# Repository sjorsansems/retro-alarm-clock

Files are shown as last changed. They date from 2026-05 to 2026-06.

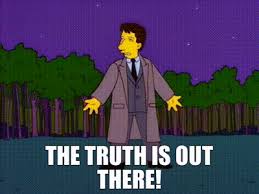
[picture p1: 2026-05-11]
animations/images.jpg

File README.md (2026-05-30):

# Retro Georgy Alarm Clock (ESP32 + MicroPython)

```text
██████╗ ███████╗████████╗██████╗  ██████╗      █████╗ ██╗      █████╗ ██████╗ ███╗   ███╗
██╔══██╗██╔════╝╚══██╔══╝██╔══██╗██╔═══██╗    ██╔══██╗██║     ██╔══██╗██╔══██╗████╗ ████║
██████╔╝█████╗     ██║   ██████╔╝██║   ██║    ███████║██║     ███████║██████╔╝██╔████╔██║
██╔══██╗██╔══╝     ██║   ██╔══██╗██║   ██║    ██╔══██║██║     ██╔══██║██╔══██╗██║╚██╔╝██║
██║  ██║███████╗   ██║   ██║  ██║╚██████╔╝    ██║  ██║███████╗██║  ██║██║  ██║██║ ╚═╝ ██║
╚═╝  ╚═╝╚══════╝   ╚═╝   ╚═╝  ╚═╝ ╚═════╝     ╚═╝  ╚═╝╚══════╝╚═╝  ╚═╝╚═╝  ╚═╝╚═╝     ╚═╝

		  8-BIT OLED ANIMATIONS  +  MP3 ALARM MUSIC  +  WS2812 LED THEMES
```


An ESP32-S3 retro alarm clock project with:
- SH1106 OLED 128x64 display and pixel animations
- DFPlayer Mini MP3 alarm playback
- WS2812 LED strip  (8 leds) effects per alarm theme
- DS3231 RTC support (with optional EEPROM schedule storage)
- WiFi time sync (NTP), weather data, and web configuration UI
- Setup AP fallback (`AlarmKlok-Setup`) when WiFi is not configured/reachable

## What We Built


This project is a complete standalone alarm device, not only a demo sketch.

Main features:
- Clock display with big 8-bit style digits
- Weekly alarm scheduling
- One-tap "skip next alarm once"
- Snooze support
- Theme-based Retro (games) alarm playback (audio + display animation + LEDs)
- A tool to convert (small) gif images to bin files which can be used as a alarmclock animation.
- OTA updates via browser
- Setup access point mode for first-time WiFi setup
- Safe boot fallback to backup app after repeated boot failures
- Built-in Phoenix-style mini Space Game (3-button controls + optional game music)

## Demo Video

A short demo video is included in:

- `video/VID_20260530_151530653.mp4`

Note: this file is stored with Git LFS. Depending on your browser/GitHub view, inline playback may not always work.
If playback is unavailable, open the file page and download it to view locally.

## 3D Print Files (STL)

3D printable enclosure/model files are included in:

- `stl files/front.stl`
- `stl files/back.stl`
- `stl files/button.stl`
- `stl files/buttonholders.stl`

You can slice and print these parts to build the physical case.

## Hardware Requirements

- 1x ESP32-S3 DevKitC-1 -> I used a N16R8, other models not tested. Enough Ram is mandantory. 
- 1x SH1106 OLED display (128x64, I2C)
- 1x DS3231 RTC module (I2C)
- Optional: AT24C32 EEPROM on RTC board (for schedule persistence)
- 1x DFPlayer Mini MP3 module + speaker
- 1x WS2812/NeoPixel LED strip (configured for 8 LEDs)
- 3x push buttons
- Wires + common GND
- Recommended: 1k resistor on ESP32 TX -> DFPlayer RX line

## Pin Mapping (Current v6)

| Function | ESP32 Pin | Notes |
|---|---:|---|
| OLED SDA | GPIO8 | SH1106 I2C bus |
| OLED SCL | GPIO9 | SH1106 I2C bus |
| RTC SDA | GPIO5 | Dedicated RTC I2C bus |
| RTC SCL | GPIO6 | Dedicated RTC I2C bus |
| DFPlayer TX (ESP->DF RX) | GPIO17 | Use 1k series resistor |
| DFPlayer RX (ESP<-DF TX) | GPIO18 | Direct is fine |
| WS2812 Data | GPIO2 | GRB byte order |
| Button UP | GPIO12 | Short: nightlight toggle, Long (3s): start Space Game |
| Button DOWN | GPIO13 | Short: OLED mode, Long: WiFi toggle |
| Button SET | GPIO14 | Short: skip next alarm once, Long: alarm edit |

## Wiring Overview

### OLED (SH1106)
- VCC -> 3.3V
- GND -> GND
- SDA -> GPIO8
- SCL -> GPIO9

### RTC (DS3231)
- VCC -> 3.3V
- GND -> GND
- SDA -> GPIO5
- SCL -> GPIO6

### DFPlayer Mini
- VCC -> 5V preferred (or stable 3.3V if your module supports it)
- GND -> GND (shared with ESP32)
- DF RX <- ESP GPIO17 (through 1k resistor)
- DF TX -> ESP GPIO18
- SPK_1/SPK_2 -> Speaker

### WS2812 LED Strip
- DIN <- GPIO2
- VCC -> external 5V (recommended)
- GND -> GND (must be shared with ESP32)

### Buttons
- One side of each button -> GPIO12 / GPIO13 / GPIO14
- Other side -> GND
- Internal pull-ups are enabled in firmware

## Software Requirements

- MicroPython firmware on ESP32-S3
- Python 3.10+ on your PC
- `mpremote` for USB deployment (optional if you only use OTA)

Optional local tooling:
- FFmpeg (audio conversion)

## Project Structure (Important Files)

- `main.py` -> boot entrypoint with safe-mode fallback logic
- `retro_georgy_alarm_klok_v6.py` -> main application
- `retro_georgy_alarm_klok_v6_backup.py` -> backup runtime target
- `index_v6.html` -> web UI served by the device
- `config_manager.py` -> config defaults/load/save
- `config.example.json` -> safe config template for repo sharing
- `neopixel_driver.py`, `dfplayer.py`, `ds3231.py` -> hardware drivers

## Installation

### 1. Flash MicroPython
Flash an ESP32-S3 MicroPython firmware compatible with your board.

### Optional: Web Installer (WLED-style)

this repo includes an ESP Web Tools setup.
But you can also install Microphthon yourself en use the Powershell script included.

- `web-installer/install.html`
- `web-installer/manifest.json`

Usage:

1. Ensure `web-installer/manifest.json` points to a valid ESP32-S3 firmware `.bin`.
2. Publish your repo with GitHub Pages.
3. Open `https://<your-user>.github.io/<your-repo>/web-installer/install.html`.
4. Click **Install Alarm Clock Firmware** and select your board serial port.

Live installer URL for this project:

- https://sjorsansems.github.io/retro-alarm-clock/web-installer/install.html

Important:

- Web Serial only works on secure pages (`https://`) in compatible browsers (Chrome/Edge).
- This web installer flashes firmware only.

After flashing, run one command in PowerShell to deploy app files:

```powershell
powershell -ExecutionPolicy Bypass -Command "iwr https://raw.githubusercontent.com/sjorsansems/retro-alarm-clock/main/tools/deploy_web_installer.ps1 -OutFile deploy_alarmklok.ps1; ./deploy_alarmklok.ps1 -Port COM7"
```

Change `COM7` if your device uses another port.

### 2. Clone the Project

```bash
git clone <your-repo-url>
cd AlarmKlok
```

### 3. Prepare Configuration

Use `config.example.json` as your base and create local `config.json` (not tracked in git).

### 4. Deploy to Device

USB deployment example:

```bash
python -m mpremote connect COM7 + cp main.py :main.py + cp retro_georgy_alarm_klok_v6.py :retro_georgy_alarm_klok_v6.py + cp retro_georgy_alarm_klok_v6_backup.py :retro_georgy_alarm_klok_v6_backup.py + cp config_manager.py :config_manager.py + cp index_v6.html :index_v6.html + cp config.json :config.json + reset
```

### 5. First Boot / Setup AP

If WiFi is not configured or unavailable, the device starts AP mode:
- SSID: `AlarmKlok-Setup`
- IP: `192.168.4.1`

Connect to that network, open the page, and save your WiFi credentials.

## Web Interface

When connected to your home network, open the device IP in your browser.

You can configure:
- Current time and seconds
- Timezone and UI language
- Alarm schedule per weekday
- Alarm test playback
- Weather location and update behavior
- WiFi behavior and setup credentials
- OTA file uploads
- GitHub Pages update checks and installs
- Retro Fact display duration and quick test
- DOS Idle Chaos screensaver behavior and daily limit
- Space Game music selection and quick start from web UI

## Automatic Updates via GitHub Pages

This project supports update checks against a GitHub Pages manifest:

- Manifest location (default): `updates/stable/manifest.json`
- Example URL: `https://sjorsansems.github.io/retro-alarm-clock/updates/stable/manifest.json`

How it works:

1. Clock checks the manifest URL.
2. If `version` is newer than the running app version, update is marked as available.
3. On install, files in manifest `files[]` are downloaded and swapped in place.
4. Clock schedules an automatic reboot.

Manifest format:

```json
{
	"version": "6.1.0",
	"channel": "stable",
	"files": [
		{
			"path": "retro_georgy_alarm_klok_v6.py",
			"url": "https://sjorsansems.github.io/retro-alarm-clock/updates/stable/retro_georgy_alarm_klok_v6.py",
			"sha256": "optional-hex-sha256"
		}
	]
}
```

Use the web UI card **GitHub Auto-Update** to:

- Enable/disable automatic checks
- Set check interval (hours)
- Change manifest URL
- Run manual check/install
- See an install progress bar while update is running

## User Guide (Buttons)

Normal clock screen:
- `UP` short press -> Nightlight ON/OFF
- `UP` long press (3s) -> Start Space Game
- `DOWN` short press -> Cycle OLED brightness modes
- `DOWN` long press -> WiFi ON/OFF
- `SET` short press -> Skip next scheduled alarm once
- `SET` long press -> Enter alarm edit mode

During alarm:
- `SET` -> Stop alarm
- `DOWN` -> Snooze (10 minutes)

During Space Game (Phoenix-style):
- `SET` (left/alarm button) -> Move ship left
- `UP` (middle/nightlight button) -> Shoot
- `DOWN` (right/dim button) -> Move ship right
- `UP` long press (3s) -> Exit game

Alarm edit mode:
- `UP` -> Hour +1
- `DOWN` -> Minute +1
- `SET` long press -> Save

## Safe Boot / Fallback Mode

`main.py` tracks startup failures.
- Primary app: `retro_georgy_alarm_klok_v6`
- Backup app: `retro_georgy_alarm_klok_v6_backup`

After repeated boot failures, it switches to backup mode automatically.

## Music and Animations

- DFPlayer supports multiple numbered tracks
- Theme mapping controls LED + animation style per alarm tone
- Additional animation binaries (`.bin`) can be uploaded via web UI

### DFPlayer MP3 File Order (Required)

`0001.mp3` is the intro track and is included in this repository.

For built-in alarm tones/animations, users should add their own files in this exact order:

1. `0001.mp3` -> Intro (already in repo)
2. `0002.mp3` -> Zelda
3. `0003.mp3` -> Mario
4. `0004.mp3` -> Synthwave
5. `0005.mp3` -> Sonic
6. `0006.mp3` -> Metroid
7. `0007.mp3` -> Pokemon
8. `0008.mp3` -> Tetris
9. `0009.mp3` -> Moonstone
10. `0010.mp3` -> Arcade
11. `0011.mp3` -> DOOM
12. `0012.mp3` -> Knight Rider
13. `0013.mp3` -> Fire
14. `0014.mp3` -> Heartbeat
15. `0015.mp3` -> Matrix
16. `0016.mp3` -> Pac-Man
17. `0017.mp3` -> Pong
18. `0018.mp3` -> Radar
19. `0019.mp3` -> Skull
20. `0020.mp3` -> Snake
21. `0021.mp3` -> Space
22. `0022.mp3` -> UFO
23. `0023.mp3` -> Donkey

Notes:

- Use zero-padded names (`0002.mp3`, not `2.mp3`).
- Place files in DFPlayer root.
- Keep numbering stable after first setup.

### Custom Uploads: Matching Music and Animations in Web UI

After uploading custom `.bin` animations in **Animaties beheren**:

1. Use the **Muziek** dropdown to choose the MP3 track mapping.
2. Use the **LED** dropdown to choose the LED theme mapping.
3. Click **Save** per animation.

This allows user-uploaded animations to use any preferred track and LED style.

### Retro Facts

When you stop the alarm, the clock can show a short retro-game fact on the display.

How it works:

1. The firmware picks a fact from a local retro-game library based on the date.
2. This works fully offline, so no internet connection is required.
3. The fact is deterministic per day, so the same date shows the same retro fact.
4. Long facts scroll vertically with a short pause before moving.

The web UI also includes a **Retro Fact Test** card so you can:

1. Set how many seconds the fact stays on screen.
2. Use the same duration for both manual test and normal alarm-stop flow.
3. Preview the local fact without triggering the alarm.

### DOS Idle Chaos

The clock now supports a DOS-style idle screensaver with random retro error scenes.

Included concepts:

1. Funny/absurd prompts
2. DOS/boot-style setup failures
3. Creepy virus-style warnings

How it behaves:

1. It triggers after configurable idle minutes.
2. Scenes switch every few seconds to look unstable.
3. A per-day maximum controls how often it can appear.
4. You can trigger it manually via **Test DOS chaos** in the web UI.

Related files:

- `create_dos_animation.py` (generator script)
- `animations/dos_meltdown.gif`
- `animations/dos_meltdown.bin`

### Space Game (Phoenix-style)

The clock now includes a compact Space Game inspired by classic fixed-shooter gameplay.

Implemented gameplay set:

1. Four classic bird-like enemy sprite variants with 2-frame flap animation.
2. Per-wave behavior patterns (march, zig-zag, and dive waves).
3. Phoenix-style cadence and tempo scaling (enemy step speed + shot burst pressure increase per wave).
4. LED strip rhythm mapped to gameplay phase (different color pulse profiles, hit flash, shot flash, wave-clear pulse).
5. Bonus mothership phase every 5th wave with its own HP bar and attack pattern.

How to start:

1. Hold the middle nightlight button (`UP`) for 3 seconds.
2. Or press **Start Space game nu** in the web UI.

Controls:

1. Left button (`SET`) moves left.
2. Middle button (`UP`) shoots.
3. Right button (`DOWN`) moves right.
4. Hold middle (`UP`) for 3 seconds to exit.

Web UI settings:

1. Use the **Space Game (Phoenix-style)** card.
2. Select game music in the dropdown (same track label style used in **Animaties beheren**).
3. Save with **Space game instellingen opslaan**.

### GIF to BIN Tool (How to Use)

You can convert small GIF animations to the `.bin` format used by the clock.

Requirements:

- Python 3.10+
- Pillow (`pip install pillow`)

Converter script:

- `tools/gif_to_frames.py`

Example command:

```bash
python tools/gif_to_frames.py --input animations/mario.gif --output animations/mario.bin --width 128 --height 64 --fps 12 --bin
```

Recommended settings:

- Keep source GIF short (2-8 seconds)
- Low frame rate (8-15 fps) to reduce file size
- High contrast source for better 1-bit conversion quality

Upload workflow:

1. Open the clock web UI.
2. Go to **Animaties beheren**.
3. Upload your generated `.bin` file.
4. Optionally map that animation to music/LED theme in the same UI.

Notes:

- Large `.bin` files may fail upload if free storage is low.
- Use `/api/storage-info` (shown in UI) to check available upload space.

See `MUSIC_GUIDE.md` for detailed music sourcing and preparation.

## Troubleshooting

No OLED output:
- Check I2C wiring and 3.3V power

No RTC detected:
- Verify DS3231 pins on dedicated bus (GPIO5/GPIO6)

No DFPlayer sound:
- Verify UART wiring, power, and shared GND
- Check speaker and SD content

No WiFi page:
- Check if AP mode is active (`AlarmKlok-Setup`)
- Otherwise verify station network connectivity

## License / Sharing Notes

- `config.json` is local-only and ignored by git
- Share `config.example.json` instead
- Do not commit personal WiFi credentials

---

```text
PRESS START TO WAKE UP.
```

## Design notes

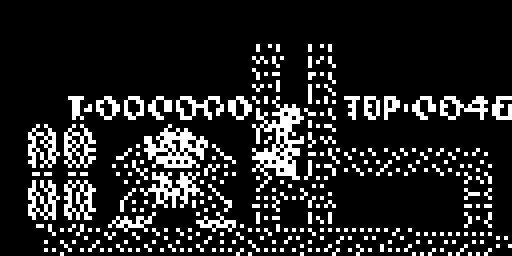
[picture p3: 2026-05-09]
donkey_preview.png

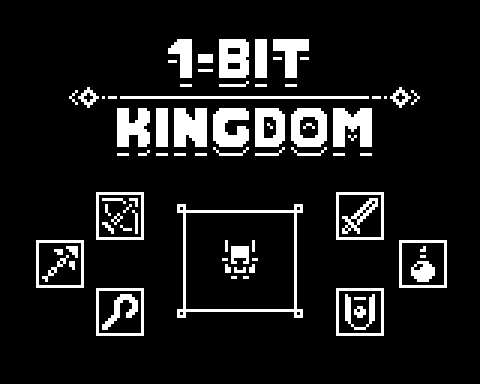
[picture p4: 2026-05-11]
animations/1bit-kingdom.gif

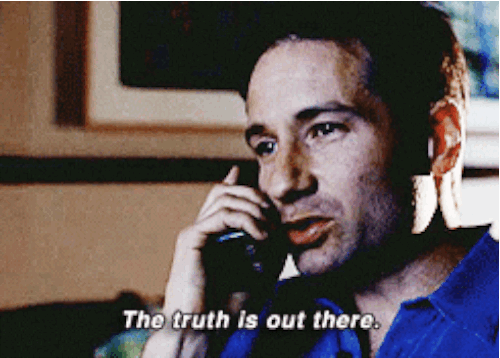
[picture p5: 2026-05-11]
animations/xfiles.gif

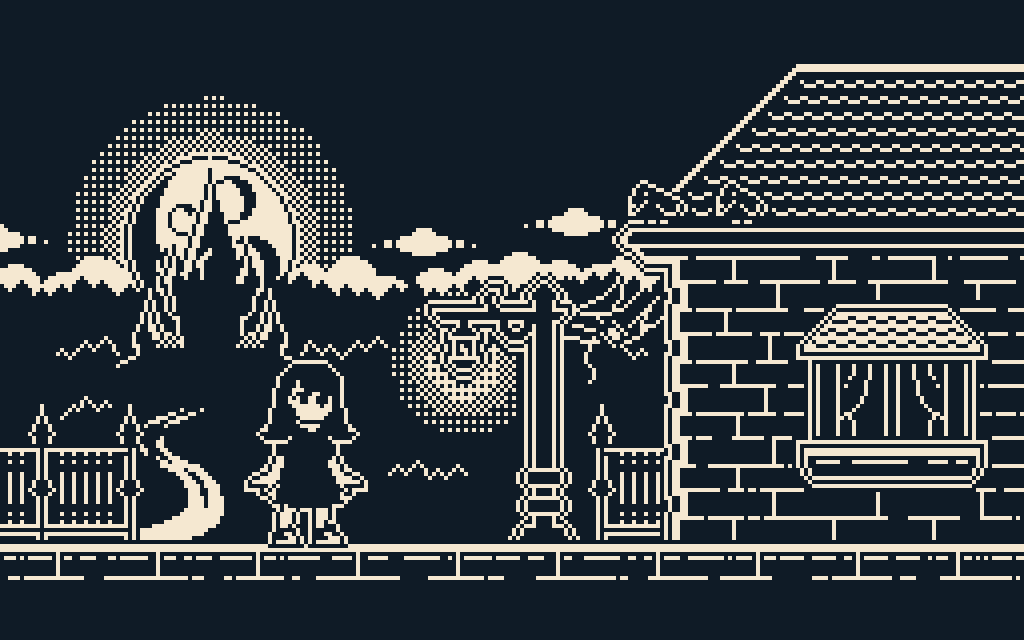
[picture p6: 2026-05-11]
animations/gothic.gif

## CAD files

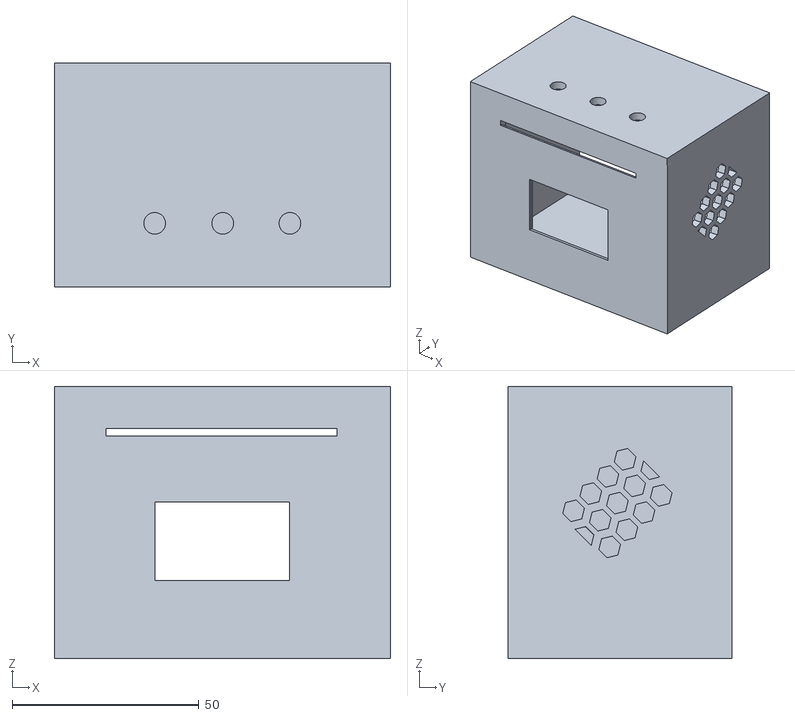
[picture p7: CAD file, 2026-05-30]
stl files/front.stl
90.0 x 60.0 x 73.0

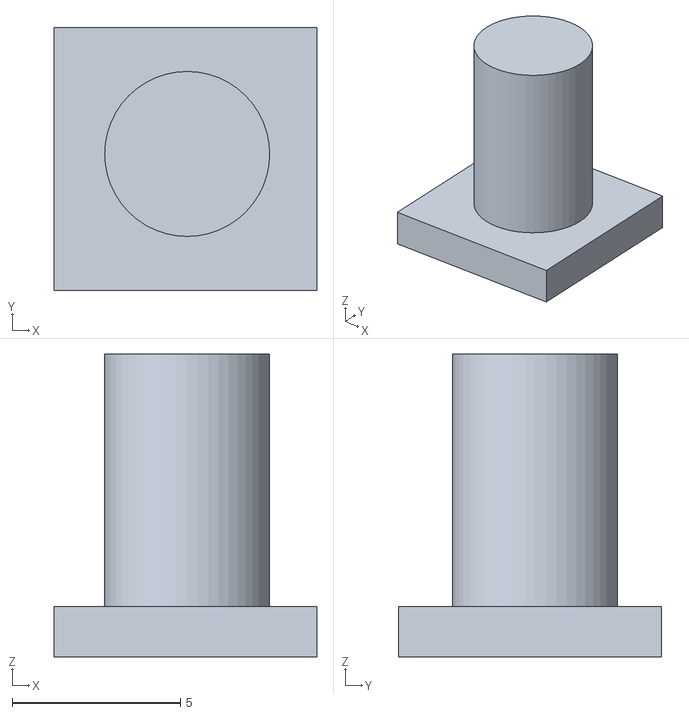
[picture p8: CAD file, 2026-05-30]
stl files/button.stl
7.80 x 7.80 x 9.00

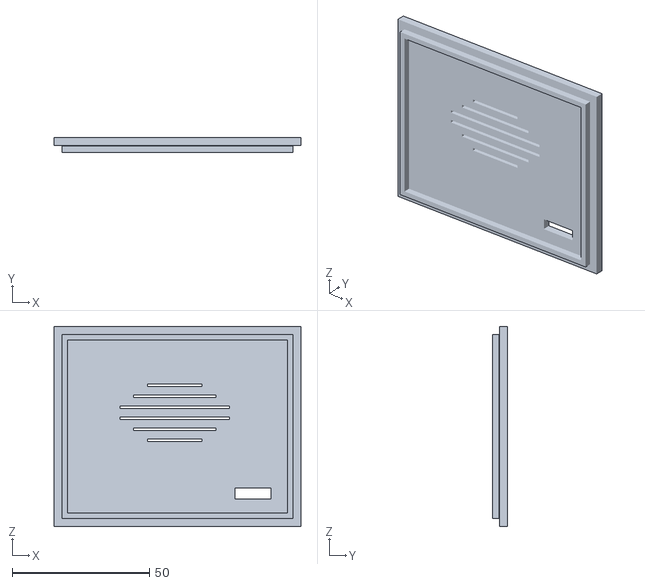
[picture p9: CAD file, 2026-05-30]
stl files/back.stl
90.0 x 5.60 x 73.0

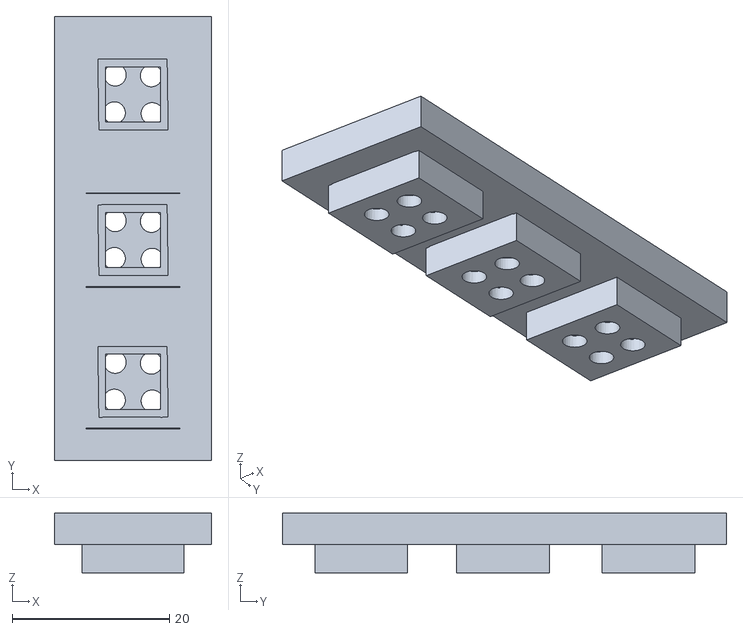
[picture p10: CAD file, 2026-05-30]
stl files/buttonholders.stl
20.0 x 56.4 x 7.60

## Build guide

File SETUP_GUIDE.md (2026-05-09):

# ESP32 Alarmklok - Setup Guide

## 📌 Hardware Verbindingen

### ESP32 Pinout Overzicht

| ESP32 Pin | Gebruik | Component | Opmerking |
|---|---|---|---|
| GPIO8 | I2C SDA | OLED (SH1106) | I2C bus voor display |
| GPIO9 | I2C SCL | OLED (SH1106) | I2C bus voor display |
| GPIO5 | I2C SDA | DS3231 RTC | Aparte I2C bus voor RTC |
| GPIO6 | I2C SCL | DS3231 RTC | Aparte I2C bus voor RTC |
| GPIO13 | Knop UP (SET) | Bedieningsknop | Ingang met pull-up, knop naar GND |
| GPIO12 | Knop DOWN (ALARM) | Bedieningsknop | Ingang met pull-up, knop naar GND |
| GPIO14 | Knop SET | Bedieningsknop | Ingang met pull-up, knop naar GND |
| GPIO17 | UART1 TX | DFPlayer Mini RX | Via 1k ohm serieweerstand |
| GPIO18 | UART1 RX | DFPlayer Mini TX | Direct verbinden |
| GPIO27 | Buzzer + | Buzzer/Speaker | Niet gebruikt in huidige versie |
| GPIO2 | LED data | WS2812 (NeoPixel) | Bitstream, byte-order GRB |
| 3.3V | Voeding + | OLED + DS3231 | Gebruik 3.3V, niet 5V |
| GND | Massa | Alle modules | Gemeenschappelijke ground |

Niet gebruikt in deze basissetup: alle overige GPIO's.

### OLED Display (I2C - 1.3" SH1106)
```
OLED Pin    ESP32 Pin
GND         GND
VCC         3.3V
SCL         GPIO9 (SCL)
SDA         GPIO8 (SDA)
```

### DS3231 RTC Module (I2C - Real-Time Clock)
```
RTC Pin     ESP32 Pin
GND         GND
VCC         3.3V
SCL         GPIO6 (SCL)  [Aparte I2C bus voor RTC]
SDA         GPIO5 (SDA)
```

### DFPlayer Mini (MP3 Player - UART)
```
DFPlayer Pin   ESP32 Pin
VCC            5V (aanbevolen) of 3.3V
GND            GND
RX             GPIO17 (UART1 TX) via 1kΩ weerstand
TX             GPIO18 (UART1 RX)
BUSY           Optioneel naar vrije GPIO (nu niet gebruikt)
SPK_1/SPK_2    Naar speaker
```

Opmerking: in de huidige code is `busy_pin=None`, dus de BUSY-lijn hoeft niet aangesloten te zijn.

### Knoppen (Pull-Up schakelaars)
```
Knop         ESP32 Pin    Functie
UP (SET)     GPIO13       Uur omhoog / Tijd modus
DOWN (ALARM) GPIO12       Minuut omhoog / Alarm modus
SET          GPIO14       Bevestigen / Alarm stoppen
```
Verbind de andere pin van elke knop met GND.

### Buzzer/Speaker (optioneel, legacy)
```
Buzzer Pin   ESP32 Pin
+ (Pos)      GPIO27 (via 330Ω weerstand)
- (Neg)      GND
```
In de huidige versie wordt de buzzer niet gebruikt; het alarm loopt via DFPlayer MP3.

## 🎯 Bedieningsinterface

### Display Mode (Standaard)
```
┌─────────────────┐
│     11:34       │
│       12s       │
│                 │
│ ALARM: 07:00    │
│ UP=TIJD DOWN=AL │
└─────────────────┘
```
- **UP knop**: Ga naar TIJD INSTELLEN modus
- **DOWN knop**: Ga naar ALARM INSTELLEN modus

### Tijd Instellen Mode
```
┌─────────────────┐
│  STEL TIJD IN   │
│                 │
│     13:45       │
│                 │
│ UP=UUR DOWN=MIN │
│ SET=OPSLAAN     │
└─────────────────┘
```
- **UP knop**: Verhoog uur (00-23)
- **DOWN knop**: Verhoog minuut (00-59)
- **SET knop**: Sla tijd op en terug naar display

### Alarm Instellen Mode
```
┌─────────────────┐
│  STEL ALARM IN  │
│                 │
│     07:00       │
│                 │
│ UP=UUR DOWN=MIN │
│ SET=OPSLAAN     │
└─────────────────┘
```
- **UP knop**: Verhoog alarm uur (00-23)
- **DOWN knop**: Verhoog alarm minuut (00-59)
- **SET knop**: Sla alarm op en terug naar display

### Alarm Afgaande
```
┌─────────────────┐
│                 │
│  ALARM AFGAAN!  │
│                 │
│ SET = UITZETTEN │
│                 │
└─────────────────┘
```
- **SET knop**: Stop de alarm buzz

## ⚙️ Instellingen (alarm_config.json)

De instellingen worden automatisch opgeslagen in `alarm_config.json`:

```json
{
    "alarm_enabled": true,
    "alarm_hour": 7,
    "alarm_minute": 0,
    "alarm_days": [1, 2, 3, 4, 5],
    "buzzer_volume": 500
}
```

- `alarm_enabled`: true/false - alarm aan/uit
- `alarm_hour`: 0-23 - uur van het alarm
- `alarm_minute`: 0-59 - minuut van het alarm
- `alarm_days`: Weekdagen [1=ma, 2=di, ..., 7=zo]
- `buzzer_volume`: PWM frequentie (250-1000 Hz)

## 🔧 I2C Pull-Up Weerstanden

Als het OLED/RTC niet detecteert wordt, voeg 4.7kΩ pull-up weerstanden toe op de gebruikte bus(sen):
- OLED bus: GPIO8 (SDA) naar 3.3V en GPIO9 (SCL) naar 3.3V
- RTC bus: GPIO5 (SDA) naar 3.3V en GPIO6 (SCL) naar 3.3V

## 📝 Eerste Start

1. Zet alle hardware aan
2. Upload `alarm_clock.py` naar ESP32 (via Thonny of esptool)
3. Het OLED scherm toont de huidige tijd (eerst standaard 00:00)
4. Druk **UP** om de huidige tijd in te stellen
5. Druk **DOWN** om het alarm in te stellen
6. Het alarm gaat af wanneer de huidige tijd het alarm uur/minuut bereikt

## 🐛 Troubleshooting

### OLED niet detecteert
- Controleer de I2C verbindingen (SDA/SCL)
- Zet pull-up weerstanden (4.7kΩ) toe op SDA en SCL
- Probeer I2C adres handmatig in code aan te passen

### DS3231 RTC niet detecteert
- Controleer voeding (3.3V)
- Zet pull-up weerstanden toe
- DS3231 gebruikt een aparte I2C bus (GPIO5/GPIO6)

### Knoppen reageren niet
- Controleer GPIO pinnen in code (GPIO13, GPIO12, GPIO14)
- Zorg dat GND verbinding goed zit
- Controleer debounce delay (200ms) - pas aan indien nodig

### MP3/DFPlayer speelt geen geluid
- Controleer UART wiring: GPIO17 -> DFPlayer RX (met 1kΩ), GPIO18 <- DFPlayer TX
- Controleer voeding van DFPlayer (liefst 5V) en gedeelde GND
- Controleer SD-kaart en bestandsnamen (`/MP3/0001.mp3`, etc.)
- Controleer speaker op `SPK_1`/`SPK_2`

## 🌈 LED Thema Kleurschema (per spel)

Bevestigde werkende WS2812 setup:
- Data pin: GPIO2
- Methode: bitstream
- Byte-order: GRB

Kleurschema per lied/spel:

1. Zelda
- Groen naar goud pulse
- R 0..200, G 200..255, B 0

2. Mario
- Rood en geel checker-patroon
- (255,0,0) en (255,255,0)

3. Synthwave
- Neon roze naar paars golf
- (255,0,100) naar (150,0,255)

4. Sonic
- Cyaan/blauw strobe
- (0,200..250,255) en (0,100,200)

5. Metroid
- Oranje naar rood (intensiteit-gedreven)
- R 255 vast, G 200..100, B 0

6. Pokemon
- Geel met rode accenten, knipperend
- (255,255,0) en (255,0,0)

7. Tetris
- Regenboogcyclus
- Rood -> oranje -> geel -> groen -> blauw -> indigo -> violet

8. Moonstone
- Maanblauw met fakkel-gouden pulse
- Basis ongeveer (40,80,180) met warme fakkel-accenten

9. Arcade
- Multicolor strobe
- Rood -> geel -> groen -> blauw -> magenta

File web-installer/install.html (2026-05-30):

# Retro Georgy Alarm Clock Web Installer

WLED-style browser flashing for ESP32-S3 (MicroPython firmware).

1. Connect your ESP32-S3 board by USB (tested: ESP32-S3 DevKitC-1 with SPIRAM).
2. Open this page in Chrome or Edge over HTTPS.
3. Click install and select your serial port.
4. After flashing, deploy project files with mpremote or OTA.

Other ESP32-S3 boards may work, but ESP32-S3 DevKitC-1 + SPIRAM is the validated target for this installer.

Configured firmware: ESP32_GENERIC_S3-SPIRAM_OCT-20260406-v1.28.0.bin

Install Alarm Clock Firmware This browser does not support Web Serial. Use Chrome or Edge. Open this page over HTTPS (or localhost) to use Web Serial.

## Step 2: Deploy App Files (One Command)

The installer above flashes MicroPython firmware only. Run this PowerShell command once to download and deploy app files.

COM Port: Copy Deploy Command

Firmware manifest: web-installer/manifest.json

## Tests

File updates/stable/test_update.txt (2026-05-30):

Retro AlarmKlok update test v6.0.1
If this file appears on the device after update, the GitHub Pages updater works.

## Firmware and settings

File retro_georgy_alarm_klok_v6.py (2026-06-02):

"""
ESP32 Retro Georgy Alarm Clock (MicroPython)
Doel: stabiel draaien op lage RAM met WiFi + NTP + retro web UI + alarm animaties.
"""

from machine import Pin, SoftI2C
import framebuf
import time
import json
import network
import socket
import gc
import esp32

try:
    import ussl as ssl
except ImportError:
    try:
        import ssl
    except ImportError:
        ssl = None

try:
    import uhashlib as hashlib
except ImportError:
    try:
        import hashlib
    except ImportError:
        hashlib = None

try:
    import ubinascii as binascii
except ImportError:
    try:
        import binascii
    except ImportError:
        binascii = None

try:
    from urllib.parse import quote
except ImportError:
    quote = None

# Agressieve garbage collection en PSRAM setup
gc.enable()
gc.collect()
try:
    esp32.memory_info()
except:
    pass
try:
    gc.threshold(gc.mem_free() // 4 + gc.mem_alloc())
except:
    pass

LOW_MEMORY_WEB_MODE = False

# WLAN lazy init — niet pre-alloceren
_WLAN = None

try:
    from config_manager import ConfigManager
except ImportError:
    ConfigManager = None

try:
    from ntp_time_sync import NTPTimeSync
except ImportError:
    NTPTimeSync = None

try:
    from ds3231 import DS3231, AT24C32
except ImportError:
    DS3231 = None
    AT24C32 = None

try:
    from dfplayer import DFPlayer
except ImportError:
    DFPlayer = None

try:
    from neopixel_driver import NeopixelDriver
except ImportError:
    NeopixelDriver = None

try:
    import neopixel
except ImportError:
    neopixel = None

# ESP32-S3 DevKitC-1 pinnen
SDA_PIN = 8   # gelabeld SDA op het board (OLED)
SCL_PIN = 9   # gelabeld SCL op het board (OLED)
DS3231_SDA_PIN = 5   # aparte I2C bus voor DS3231 RTC
DS3231_SCL_PIN = 6
I2C_FREQ = 100_000
# Buzzer uitgeschakeld — DFPlayer MP3 wordt gebruikt als alarm

# DFPlayer Mini: ESP32-S3 DevKitC-1
# GPIO17 = UART1 TX (gelabeld TXD1) -> 1kΩ -> DFPlayer RX
# GPIO18 = UART1 RX (gelabeld RXD1) <--------- DFPlayer TX
# Optioneel: BUSY-pin (actief-laag als er afgespeeld wordt)
DFPLAYER_UART_ID  = 1
DFPLAYER_TX_PIN   = 17
DFPLAYER_RX_PIN   = 18
DFPLAYER_BUSY_PIN = None   # bijv. 4 als je de BUSY-pin aansluit
DFPLAYER_TRACK    = 1      # track-nummer dat tijdens alarm afgespeeld wordt (1.mp3 op SD)

# WS2812B Addressable LEDs (8-LED strip)
WS2812_PIN = 2  # bevestigd werkend: GPIO2 + bitstream + GRB
WS2812_COUNT = 8  # 8 LEDs
# Onboard status LED/RGB on many ESP32-S3 dev boards (best effort)
BOARD_LED_PIN = 48
WIDTH = 128
HEIGHT = 64
SH1106_COL_OFFSET = 2
WIFI_PORT = 80
WEBSERVER_START_DELAY_MS = 0
WIFI_MANUAL_ON_MS = 120000
WIFI_DAILY_CHECK_MS = 60000
WIFI_DAILY_RETRY_MS = 3600000
WIFI_MIN_FREE_HEAP = 35000
WIFI_CONNECT_TIMEOUT_S = 8
DEFAULT_WIFI_SSID = ""
SETUP_AP_SSID = "AlarmKlok-Setup"
SETUP_AP_IP = "192.168.4.1"
WIFI_HOSTNAME = "alarmklok"
ALARM_INTRO_MS = 2500
ALARM_BOSS_MS = 20000
ALARM_AUTO_STOP_MS = 15 * 60 * 1000
NIGHT_DIM_START_HOUR = 22
NIGHT_DIM_END_HOUR = 7
UP_BUTTON_PIN = 12    # Touch12 / ADC2_1 — omgewisseld op verzoek
DOWN_BUTTON_PIN = 13  # Touch13 / ADC2_2 — omgewisseld op verzoek
SET_BUTTON_PIN = 14   # Touch14 / ADC2_3 — vrij
BUTTON_DEBOUNCE_MS = 60
BUTTON_SHORT_MIN_MS = 70
BUTTON_SHORT_MIN_MS_GAME = 45
DAY_KEYS = ("mon", "tue", "wed", "thu", "fri", "sat", "sun")
APP_VERSION = "6.1.11"
DEFAULT_UPDATE_MANIFEST_URL = "https://sjorsansems.github.io/retro-alarm-clock/updates/stable/manifest.json"
ANIMATIONS_DIR = "animations"
DEFAULT_RETRO_FACT_DISPLAY_SECONDS = 10
DEFAULT_DOS_IDLE_ENABLED = True
DEFAULT_DOS_IDLE_TRIGGER_MINUTES = 6
DEFAULT_DOS_IDLE_MAX_PER_DAY = 12
RETRO_FACT_LIBRARY = [
    "1977: Atari released the VCS, later known as the Atari 2600",
    "1980: Pac-Man turned arcades into a global phenomenon",
    "1983: Nintendo launched the Famicom in Japan",
    "1985: Super Mario Bros. launched in Japan and reshaped platform games",
    "1986: The Legend of Zelda debuted and defined adventure design",
    "1987: Zelda II pushed the series into a more experimental direction",
    "1988: Sega launched the Mega Drive and started a new console war",
    "1989: Nintendo launched the Game Boy and handheld gaming exploded",
    "1990: The Super Famicom arrived and raised the bar for 16-bit games",
    "1991: Sonic the Hedgehog introduced Sega's fastest mascot",
    "1992: Mortal Kombat made arcades louder, stranger, and bloodier",
    "1993: DOOM changed first-person shooters forever",
    "1994: Sony entered the console market with the original PlayStation",
    "1995: Chrono Trigger became a legendary JRPG favorite",
    "1996: Nintendo 64 brought 3D gaming to the mainstream",
    "1997: Final Fantasy VII made JRPGs a global event",
    "1998: Sega released the Dreamcast in Japan, a cult retro classic",
    "1999: Shenmue showed how ambitious open-world storytelling could be",
    "2000: The PlayStation 2 launched and became a massive success",
    "2001: The Game Boy Advance kept handheld gaming strong",
    "2002: The GameCube gave Nintendo a compact purple powerhouse",
    "2004: The Nintendo DS made touch controls a mainstream idea",
    "2005: The Xbox 360 kicked off the HD console era",
    "2006: The Wii made motion controls a household concept",
    "2007: Super Mario Galaxy proved 3D platforming could still surprise",
    "2008: Braid helped define the indie game boom",
    "2009: Minecraft began its rise from small experiment to phenomenon",
    "2010: Kinect made camera-controlled gaming a headline feature",
    "2011: The Legend of Zelda: Skyward Sword arrived with motion controls",
    "2012: The Wii U introduced a second-screen console idea",
    "2013: The PlayStation 4 launched and set up the modern era",
    "2014: Shovel Knight became an instant retro-inspired classic",
    "2015: Undertale showed how much personality a small game could have",
    "2016: Pokémon Go turned real-world streets into game maps",
    "2017: The Nintendo Switch blended handheld and home gaming",
    "2018: Celeste became a standout example of modern pixel-art design",
    "2019: The Sega Genesis Mini brought 16-bit nostalgia back again",
    "2020: The Xbox Series X|S opened the latest console generation",
    "2021: Metroid Dread brought 2D action back into the spotlight",
    "2022: Atari 50 celebrated the long history of arcade and console gaming",
    "2023: The Legend of Zelda: Tears of the Kingdom became a major launch moment",
    "2024: Retro gaming kept thriving through remakes, minis, and indie tributes",
]

DOS_IDLE_SCENES = [
    {
        "concept": "grappig",
        "lines": [
            "C:\\> load retro",
            "ERR: coffee.sys",
            "Retry [Y/N]?",
        ],
        "footer": "C:\\>_",
    },
    {
        "concept": "grappig",
        "lines": [
            "Error 274:",
            "Keyboard missing",
            "Press F1... nope",
        ],
        "footer": "C:\\> help",
    },
    {
        "concept": "grappig",
        "lines": [
            "No memory for",
            "Wolfenstein 3-D",
            "Close TSRs",
        ],
        "footer": "MEM FREE: 12K",
    },
    {
        "concept": "boot",
        "lines": [
            "Setup failed:",
            "MS-DOS 6.22",
            "Install aborted",
        ],
        "footer": "Press F3 reboot",
    },
    {
        "concept": "boot",
        "lines": [
            "HIMEM.SYS loaded",
            "EMM386 failed",
            "Continue anyway",
        ],
        "footer": "C:\\> win /3",
    },
    {
        "concept": "boot",
        "lines": [
            "A:\\ DRIVE ERROR",
            "B:\\ DRIVE ERROR",
            "C:\\ maybe OK",
        ],
        "footer": "Retry/Abort/Fail",
    },
    {
        "concept": "creepy",
        "lines": [
            "Virus found in",
            "CLOCK.EXE",
            "Quarantine failed",
        ],
        "footer": "SCAN CODE: 0xDEAD",
    },
    {
        "concept": "creepy",
        "lines": [
            "MEM MANAGER",
            "NOT INSTALLED",
            "SYSTEM UNSTABLE",
        ],
        "footer": "C:\\> _",
    },
    {
        "concept": "creepy",
        "lines": [
            "SYSTEM HALTED",
            "CLOCK CORE LOCKED",
            "...just kidding",
        ],
        "footer": "Press any key",
    },
]

# Phoenix-style bird sprites for the Space Game (4 variants, 2 flap frames each).
# Each sprite frame is a tiny 8x5 bitmap encoded as strings.
SPACE_BIRD_SPRITES = {
    0: (
        (
            "00100100",
            "01111110",
            "11111111",
            "01111110",
            "00111100",
        ),
        (
            "01000010",
            "00111100",
            "11111111",
            "00111100",
            "01011010",
        ),
    ),
    1: (
        (
            "00011000",
            "01111110",
            "11111111",
            "00111100",
            "01100110",
        ),
        (
            "01000010",
            "00111100",
            "11111111",
            "01111110",
            "00011000",
        ),
    ),
    2: (
        (
            "00111100",
            "11111111",
            "01111110",
            "00111100",
            "01011010",
        ),
        (
            "01000010",
            "11111111",
            "00111100",
            "01111110",
            "00100100",
        ),
    ),
    3: (
        (
            "01100110",
            "00111100",
            "11111111",
            "01111110",
            "00011000",
        ),
        (
            "00011000",
            "01111110",
            "11111111",
            "00111100",
            "01100110",
        ),
    ),
}

# Aantal MP3-nummers op de SD-kaart (lied 1 t/m N)
DFPLAYER_TRACK_COUNT = 30
SCHEDULE_NAMED_TONE_MAX = 24
ALARM_REPEAT_MS = 45000  # herstart track pas na ruime speeltijd (voorkomt vroeg afkappen)

# Koppel GIF-namen aan een alarm-tone (muziek + LEDs).
# Voeg hier nieuwe GIFs toe die je aan een specifiek liedje wilt koppelen.
# Waarde None = geen koppeling, gebruiker kiest zelf tone.
GIF_TONE_MAP = {
    "mario": "2",
    "zelda": "1",
    "doom":  "10",
    "knight_rider": "11",
}


def get_alarm_tone_options():
    labels = {
        1: "Zelda", 2: "Mario", 3: "Synthwave", 4: "Sonic", 
        5: "Metroid", 6: "Pokemon", 7: "Tetris", 8: "Moonstone", 9: "Arcade",
        10: "DOOM", 11: "Knight Rider", 12: "Fire", 13: "Heartbeat",
        14: "Matrix", 15: "Pac-Man", 16: "Pong", 17: "Radar",
        18: "Skull", 19: "Snake", 20: "Space", 21: "UFO", 22: "Donkey",
        23: "Random Mix", 24: "IT Crowd Intro"
    }
    schemes = {
        1: "Groen -> goud pulse",
        2: "Rood/geel checker",
        3: "Neon roze -> paars golf",
        4: "Cyaan/blauw strobe",
        5: "Oranje -> rood",
        6: "Geel met rode accenten",
        7: "Regenboog cyclus",
        8: "Maanblauw met fakkel-goud pulse",
        9: "Multicolor strobe",
        10: "Helrood/oranje doom flicker",
        11: "Rode scanner sweep",
        12: "Vlammen rood -> geel",
        13: "Dubbele hartslag pulse",
        14: "Groene matrix rain",
        15: "Pac-Man chase + ghost",
        16: "Pong bal met paddles",
        17: "Radar sweep + ping",
        18: "Bone-white flashes + paars",
        19: "Snake head/tail chase",
        20: "Space twinkle stars",
        21: "UFO beam + hull pulse",
        22: "Retro amber/brown arcade",
        23: "Pseudo-random mix van alle LED themes",
        24: "CRT/glitch intro (IT Crowd vibe)",
    }
    return [
        {
            "key": str(i),
            "label": labels.get(i, "Lied {}".format(i)),
            "scheme": schemes.get(i, "Onbekend"),
        }
        for i in range(1, DFPLAYER_TRACK_COUNT + 1)
    ]


BIG_TIME_GLYPHS = {
    "0": ("111", "101", "101", "101", "111"),
    "1": ("010", "110", "010", "010", "111"),
    "2": ("111", "001", "111", "100", "111"),
    "3": ("111", "001", "111", "001", "111"),
    "4": ("101", "101", "111", "001", "001"),
    "5": ("111", "100", "111", "001", "111"),
    "6": ("111", "100", "111", "101", "111"),
    "7": ("111", "001", "001", "001", "001"),
    "8": ("111", "101", "111", "101", "111"),
    "9": ("111", "101", "111", "001", "111"),
    ":": ("0", "1", "0", "1", "0"),
}

_HTML_FILE = "index_v6.html"
_HTML_FILE_LITE = "index_lite.html"


def _send_all(sock, data):
    view = memoryview(data)
    while len(view):
        sent = sock.send(view)
        if sent is None or sent <= 0:
            break
        view = view[sent:]


def _send_html_response(sock, filename):
    _send_all(sock, b"HTTP/1.1 200 OK\r\nContent-Type: text/html\r\nConnection: close\r\n\r\n")
    try:
        with open(filename, "rb") as f:
            while True:
                chunk = f.read(512)
                if not chunk:
                    break
                _send_all(sock, chunk)
    except Exception as e:
        body = "<html><body>Fout: kan {} niet laden: {}</body></html>".format(filename, e)
        _send_all(sock, body.encode())


# HTML wordt van disk naar socket gestreamd via _send_html_response() - niet in RAM opgeslagen.
def enable_low_memory_web_mode():
    global LOW_MEMORY_WEB_MODE
    if LOW_MEMORY_WEB_MODE:
        return
    LOW_MEMORY_WEB_MODE = True
    gc.collect()


class SH1106_I2C(framebuf.FrameBuffer):
    def __init__(self, width, height, i2c, addr=0x3C):
        self.width = width
        self.height = height
        self.i2c = i2c
        self.addr = addr
        self.pages = height // 8
        self.buffer = bytearray(self.pages * width)
        super().__init__(self.buffer, width, height, framebuf.MONO_VLSB)
        for cmd in (0xAE, 0xD5, 0x80, 0xA8, self.height - 1, 0xD3, 0x00, 0x40,
                    0xAD, 0x8B, 0xA1, 0xC8, 0xDA, 0x12, 0x81, 0x7F, 0xD9, 0x22,
                    0xDB, 0x35, 0xA4, 0xA6, 0xAF):
            self.i2c.writeto(self.addr, bytes((0x80, cmd)))
        self._contrast = 0x7F
        self._display_on = True
        self.fill(0)
        self.show()

    def set_contrast(self, value):
        value = max(0, min(255, int(value)))
        if value == self._contrast:
            return
        self.i2c.writeto(self.addr, bytes((0x80, 0x81)))
        self.i2c.writeto(self.addr, bytes((0x80, value)))
        self._contrast = value

    def display_on(self, enabled=True):
        enabled = bool(enabled)
        if enabled == self._display_on:
            return
        self.i2c.writeto(self.addr, bytes((0x80, 0xAF if enabled else 0xAE)))
        self._display_on = enabled

    def show(self):
        for page in range(self.pages):
            self.i2c.writeto(self.addr, bytes((0x80, 0xB0 + page)))
            col = SH1106_COL_OFFSET
            self.i2c.writeto(self.addr, bytes((0x80, col & 0x0F)))
            self.i2c.writeto(self.addr, bytes((0x80, 0x10 | (col >> 4))))
            start = self.width * page
            self.i2c.writeto(self.addr, b"\x40" + self.buffer[start:start + self.width])


class WiFiManagerLite:
    def __init__(self, ssid, password, timeout=WIFI_CONNECT_TIMEOUT_S):
        self.ssid = ssid
        self.password = password
        self.timeout = timeout
        global _WLAN
        if _WLAN is None:
            # Agressieve RAM cleanup voordat WiFi wordt geladen
            for _ in range(3):
                gc.collect()
                time.sleep(0.1)
            try:
                _WLAN = network.WLAN(network.STA_IF)
                # WLAN voorbij initi, nog niet actief
            except Exception as e:
                print("! WiFi pre-init fout, retrying...")
                for _ in range(5):
                    gc.collect()
                    time.sleep(0.1)
                try:
                    _WLAN = network.WLAN(network.STA_IF)
                except Exception:
                    raise OSError("WiFi Out of Memory")
        self.sta = _WLAN

    def connect(self):
        try:
            if self.sta.isconnected():
                return True
        except:
            pass

        if not self.ssid:
            print("! WiFi fout: SSID is leeg")
            return False

        try:
            # Minder agressief dan telkens active(False)->active(True),
            # want dat kan op sommige firmware builds instabiel zijn.
            if not self.sta.active():
                self.sta.active(True)
            time.sleep(0.5)

            # Zet een herkenbare netwerknaam voor DHCP/local DNS waar ondersteund.
            try:
                self.sta.config(dhcp_hostname=WIFI_HOSTNAME)
                print("WiFi hostname:", WIFI_HOSTNAME)
            except Exception:
                try:
                    network.hostname(WIFI_HOSTNAME)
                    print("WiFi hostname:", WIFI_HOSTNAME)
                except Exception:
                    pass

            # Begin met een schone connect-staat.
            try:
                self.sta.disconnect()
            except:
                pass

            print("WiFi: verbinden met '{}'...".format(self.ssid))
            self.sta.connect(self.ssid, self.password)
            start = time.ticks_ms()
            while not self.sta.isconnected():
                st = self.sta.status()
                # ESP32 statuscodes: -3 wrong password, -2 no AP, -1 fail
                if st in (-3, -2, -1):
                    if st == -3:
                        print("! WiFi fout: verkeerd wachtwoord")
                    elif st == -2:
                        print("! WiFi fout: SSID niet gevonden (2.4GHz?)")
                    else:
                        print("! WiFi fout: connect mislukt")
                    return False
                if time.ticks_diff(time.ticks_ms(), start) > self.timeout * 1000:
                    print("! WiFi timeout na {}s, status={}".format(self.timeout, self.sta.status()))
                    return False
                time.sleep(0.3)
                gc.collect()  # Agressieve GC tijdens connect
            ip = self.sta.ifconfig()[0]
            print("✓ WiFi verbonden, IP={}".format(ip))
            return True
        except KeyboardInterrupt:
            # Laat app doorlopen zonder crash als connect wordt onderbroken.
            print("! WiFi connect onderbroken")
            try:
                self.sta.disconnect()
            except:
                pass
            return False
        except Exception as e:
            print("! WiFi connect fout:", e)
            gc.collect()
            return False

    def is_connected(self):
        try:
            return self.sta and self.sta.isconnected()
        except:
            return False

    def get_ip(self):
        try:
            if self.is_connected():
                return self.sta.ifconfig()[0]
        except:
            pass
        return None
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

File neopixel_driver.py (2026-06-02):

"""
WS2812B Neopixel LED driver for 8-LED strip
GPIO2 on ESP32-S3 DevKitC-1
"""
import machine
import time

try:
    import neopixel
except ImportError:
    neopixel = None

_HAS_BITSTREAM = hasattr(machine, "bitstream")
_WS2812_TIMING = (400, 850, 800, 450)

# Documented LED palette reference per alarm tone (1..9).
TONE_COLOR_SCHEMES = {
    "1": "Zelda: green->gold pulse (R 0..200, G 200..255, B 0)",
    "2": "Mario: red/yellow checker ((255,0,0) <-> (255,255,0))",
    "3": "Synthwave: neon pink->purple wave ((255,0,100) <-> (150,0,255))",
    "4": "Sonic: cyan/blue strobe ((0,200..250,255) <-> (0,100,200))",
    "5": "Metroid: orange->red by intensity (R 255, G 200..100, B 0)",
    "6": "Pokemon: yellow with red accents ((255,255,0) + (255,0,0))",
    "7": "Tetris: rainbow cycle (red->orange->yellow->green->blue->indigo->violet)",
    "8": "Moonstone: moon-blue and torch-gold pulse ((40,80,180) + (255,140,20))",
    "9": "Arcade: multicolor strobe (red->yellow->green->blue->magenta)",
}

class NeopixelDriver:
    def __init__(self, pin=2, num_leds=8):
        """Initialize WS2812B strip on specified pin."""
        if isinstance(pin, (tuple, list)):
            self.pins = [machine.Pin(p, machine.Pin.OUT) for p in pin]
            self.pin_numbers = tuple(pin)
        else:
            self.pins = [machine.Pin(pin, machine.Pin.OUT)]
            self.pin_numbers = (pin,)
        self.num_leds = num_leds
        # Keep a logical GRB buffer so existing theme code remains unchanged.
        self.buf = bytearray(num_leds * 3)  # RGB * 8
        # timing=1 -> 800kHz (WS2812/WS2812B)
        self.np = [neopixel.NeoPixel(pin_obj, self.num_leds, bpp=3, timing=1) for pin_obj in self.pins] if neopixel else None
        self.brightness = 92  # Start at 36% to avoid power supply overload
        self._clear()
        self.show()
    
    def _write(self):
        """Write current buffer to strip using hardware-backed NeoPixel timing."""
        if self.np is not None:
            for strip in self.np:
                for i in range(self.num_leds):
                    o = i * 3
                    g = self.buf[o]
                    r = self.buf[o + 1]
                    b = self.buf[o + 2]
                    strip[i] = (r, g, b)
                strip.write()
            return

        if _HAS_BITSTREAM:
            for pin_obj in self.pins:
                machine.bitstream(pin_obj, 0, _WS2812_TIMING, self.buf)
            return

        # Fallback: bit-bang timing for firmwares without neopixel module.
        for pin_obj in self.pins:
            for byte in self.buf:
                for i in range(8):
                    pin_obj(1)
                    if byte & (0x80 >> i):
                        time.sleep_us(4)
                    else:
                        time.sleep_us(2)
                    pin_obj(0)
                    time.sleep_us(2)
        time.sleep_us(50)
    
    def _clear(self):
        """Clear all LEDs."""
        self.buf[:] = bytearray(self.num_leds * 3)
    
    def set_pixel(self, index, r, g, b):
        """Set pixel color (applies brightness)."""
        if 0 <= index < self.num_leds:
            # Apply brightness
            r = (r * self.brightness) // 255
            g = (g * self.brightness) // 255
            b = (b * self.brightness) // 255
            self.buf[index * 3] = g  # WS2812 uses GRB format
            self.buf[index * 3 + 1] = r
            self.buf[index * 3 + 2] = b
    
    def set_all(self, r, g, b):
        """Set all LEDs to same color."""
        for i in range(self.num_leds):
            self.set_pixel(i, r, g, b)
    
    def show(self):
        """Update LED strip."""
        self._write()
    
    def clear(self):
        """Turn off all LEDs."""
        self._clear()
        self.show()
    
    def set_brightness(self, level):
        """Set brightness 0-255."""
        self.brightness = max(0, min(255, level))
    
    def sunrise_effect(self, duration_ms=120000, callback=None):
        """
        Sunrise effect: gradual warm white fade up.
        Default 2 minutes, can be interrupted by callback returning True.
        """
        start = time.ticks_ms()
        steps = 100
        
        for step in range(steps + 1):
            if callback and callback():  # Allow early exit
                break
            
            elapsed = time.ticks_diff(time.ticks_ms(), start)
            progress = min(1.0, elapsed / duration_ms)
            current_step = int(progress * steps)
            
            if current_step > step:
                # Warm sunrise colors: deep red → orange → yellow → white
                if current_step < 25:
                    # Deep red → orange
                    ratio = current_step / 25
                    r = int(100 + 155 * ratio)
                    g = int(20 + 80 * ratio)
                    b = 0
                elif current_step < 50:
                    # Orange → yellow
                    ratio = (current_step - 25) / 25
                    r = 255
                    g = int(100 + 155 * ratio)
                    b = 0
                elif current_step < 75:
                    # Yellow → warm white
                    ratio = (current_step - 50) / 25
                    r = 255
                    g = 255
                    b = int(100 * ratio)
                else:
                    # Full warm white
                    r, g, b = 255, 255, 150
                
                self.set_all(r, g, b)
                self.show()
            
            time.sleep_ms(50)
    
    # ============ PER-LIEDJE THEMA'S ============
    
    def theme_zelda(self, frame, intensity):
        """Liedje 1: Zelda - Green to gold pulsing."""
        pulse = abs((frame % 30) - 15) / 15  # 0-1-0
        r = int(200 * pulse)
        g = int(200 + 55 * pulse)
        b = 0
        self.set_all(r, g, b)
        self.show()
    
    def theme_mario(self, frame, intensity):
        """Liedje 2: Mario - Red/yellow jumping pattern."""
        phase = frame % 24
        for i in range(self.num_leds):
            if (i + phase // 6) % 2 == 0:
                # Red
                self.set_pixel(i, 255, 0, 0)
            else:
                # Yellow
                self.set_pixel(i, 255, 255, 0)
        self.show()
    
    def theme_synthwave(self, frame, intensity):
        """Liedje 3: Synthwave - Neon pink/purple wave."""
        for i in range(self.num_leds):
            wave = (frame + i * 4) % 40
            if wave < 20:
                # Pink
                brightness = wave / 20
                self.set_pixel(i, int(255 * brightness), 0, int(100 * brightness))
            else:
                # Purple
                brightness = (40 - wave) / 20
                self.set_pixel(i, int(150 * brightness), 0, int(255 * brightness))
        self.show()
    
    def theme_sonic(self, frame, intensity):
        """Liedje 4: Sonic - Cyan/blue speed strobe."""
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

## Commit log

2026-05-05 Transitie-animaties: LEDs alleen bij opstart/webtest, niet bij uur-omslag
2026-05-09 Fix animation manager label mapping for music and LED numbering
2026-05-09 Fix schedule save behavior, button responsiveness, and alarm track playback mapping
    [retro_georgy_alarm_klok_v6.py]
2026-05-30 Fix ESP32-S3 OCT firmware path in web installer
2026-05-30 Add GitHub Pages auto-update flow and remove obsolete firmware bins
2026-05-30 Clarify validated ESP32-S3 target in web installer
2026-05-30 Publish ESP32-S3 firmware binary for web installer
2026-05-30 Add one-command app deploy flow to web installer
2026-05-30 Add demo video (LFS) and 3D STL files with README updates
    [back.stl, button.stl, buttonholders.stl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]
2026-05-30 Fix retro fact vertical scrolling
    [retro_georgy_alarm_klok_v6.py]
2026-06-02 Release 6.1.8: harden buttons against ghost presses
2026-06-02 Release 6.1.8: fix skip feedback overlap and text clarity
    [retro_georgy_alarm_klok_v6.py]
2026-06-02 Release 6.1.8: update skip text to include eenmalig
    [retro_georgy_alarm_klok_v6.py]
2026-06-02 Release 6.1.9: alarm skip popup betere teksten, geen OLED overlap
    [retro_georgy_alarm_klok_v6.py]
2026-06-02 Release 6.1.11: add Random Mix and IT Crowd Intro LED themes
